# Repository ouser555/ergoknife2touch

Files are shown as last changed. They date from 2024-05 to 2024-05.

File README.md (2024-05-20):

# ergoknife2touch

### imgur link

* imgur pic link
  https://imgur.com/a/k03YgLD
* imgur demo video link
  https://imgur.com/5lGmcCW

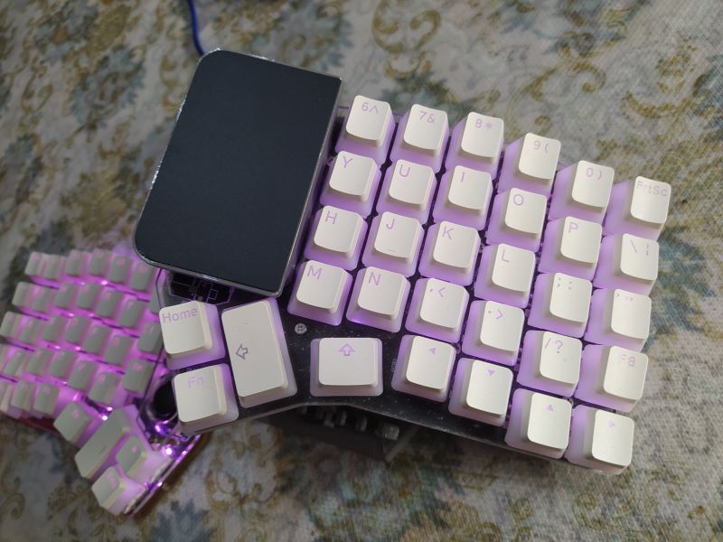
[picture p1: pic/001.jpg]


延續了前一代Ergoknife分體鍵盤，更換了一些性能更強的組件，保留用螺絲調整的傾斜設計。

照片上看到的鍵盤都是一樣的透明色，差別只是有還沒撕膠膜的或是裝了特別的鍵帽，

或是開了燈效，都還是同一組鍵盤。

所有組件都可以靠一隻螺絲起子簡易拆裝的設計，更換部件清潔都很方便。

連接左右鍵盤只需要普通的3.5mm音源線即可，選擇會比較多。

.

* 左手配置一組Trackpoint和OLED螢幕，右手則改成了支援多指的觸控板。

.

* 這次的 Trackpoint 的設計改採用 Joycon 類比搖桿加上trackpad來替代先前的數位壓力式模組，

  精準度與可操控性都有提升，

* 在軟體方面也特別改成可以分別切換左手Trackpoint的功能和右手trackpad的功能

  當前狀態也會顯示在OLED螢幕上。

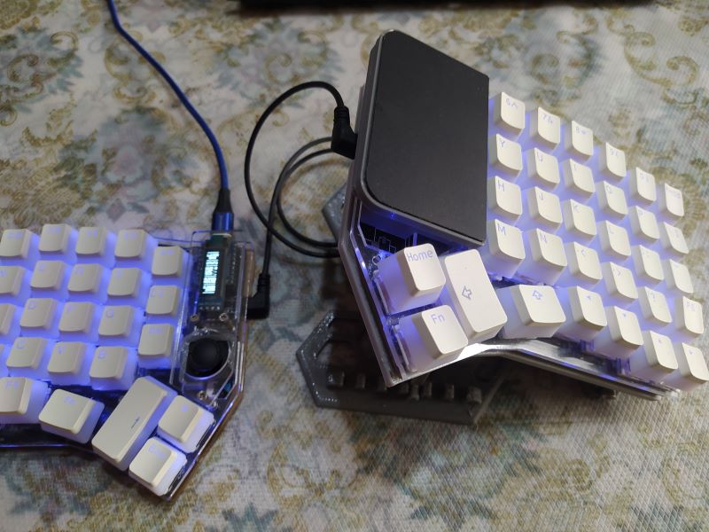
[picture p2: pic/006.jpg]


* 左手trackpoint功能說明

  1. 滑鼠移動

  2. 滾輪上下左右

  3. WASD 四向鍵

  4. UWASD 自訂義四向鍵 可用VIA設定

  5. JOYSTICK R 左搖桿

  6. JOYSTICK R 右搖桿

  7. JOYSTICK Z 板機類比

.

其中搖桿的功能可配合其他搖桿軟體設置更多操作，
	
但此鍵盤並非設定為遊戲用鍵盤，搖桿的設定只是為了提供更多靈活性的考量，
	
所以遊戲使用的精準度就不是在保證的功能範圍內了。

.

搖桿中鍵功能沒有打開，因為該鍵需要的操作力度過大，怕影響機構壽命所以不開放此功能。
	
有這個需求的，剛好自己會改軟體的使用者，可以自己修改，硬體線路都有保留。
	
硬體有預留一組滾輪編碼器/旋轉編碼器的接口，使用者也可以自行飛線改裝。

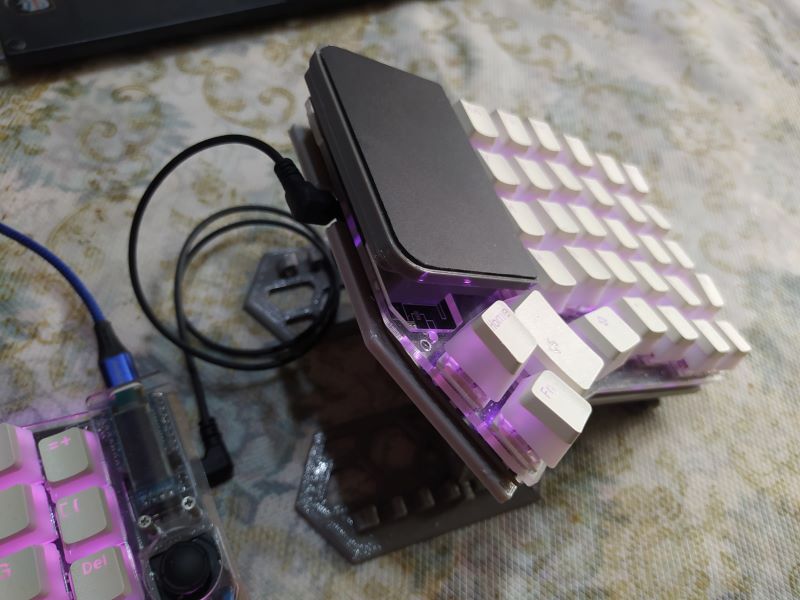
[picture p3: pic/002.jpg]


* 右手trackpad功能說明

  1. 單指滑動為普通滑鼠鼠標。

  2. 單指點擊>滑鼠左鍵。

  3. 雙指點擊>滑鼠右鍵。

  4. 三指按住0.5秒後放開>自定義按鍵 user0，預設為中鍵。

  5. 雙指往四個方向划動>四向滾輪。

  6. 雙指放大縮小>此手勢分別有三種設定

     a. 對普通網頁或編輯器的 zoom in/out，其實就是一般ctrl+滾輪的功能。

     b. 音量調整up/dowm。

     c. 自定義按鍵，user 5、6。 

     d. 關閉此功能，由於某些人可能容易把雙指的滾輪和這個放大縮小的手勢搞混，比方手抖造成的誤操作，所以也讓使用這能夠關閉這個功能。

  7. 單指4向swipe，通過單指快速往四個方向掃掠分別對應到四個可自定義按鍵，user 1、2、3、 4預設為數字小鍵盤4、6、2、8。

     由於這個操作也是要依靠使用者的習慣及熟練度才能有較好的體驗，所以如果想關閉這個功能就直接把user 1、2、3、4鍵依喜好設成無按鍵即可。

  8. 雖然這個觸控板硬體性能可以支援到5指，但此觸控板的機構條件，實在是很難再放下更多手指了，所以這應該是比較合理的配置了。

  9. 為了在這個尺寸上合理的放置觸控板，所以犧牲了3個普通按鍵的鍵位，總按鍵數為35+32=67鍵，

     但觸控板提供的手勢自定義按鍵也達到了7鍵，所以可操控性實質上增加了。

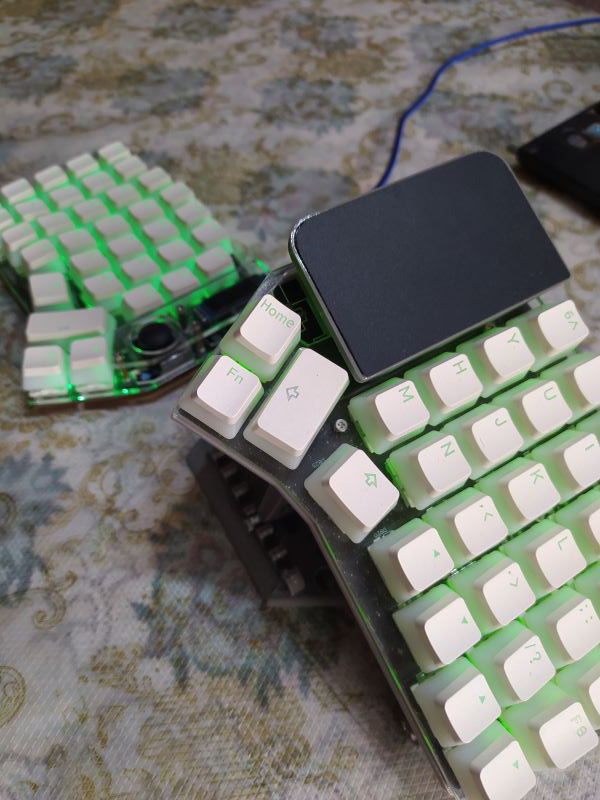
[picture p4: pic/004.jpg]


此款鍵盤打開了大部分的RGB燈效，因為還沒針對此功能拍影片，所以可以先參考連結中其他鍵盤的功能展示

https://www.youtube.com/shorts/bci9zSVapj8  (相似度很高，音效是電腦端發出的)

https://www.youtube.com/watch?v=7f3usatOIKM (分體鍵盤的表現會稍有不同)

.

自己拍的部分效果展示，

https://imgur.com/a/ag3FOmy

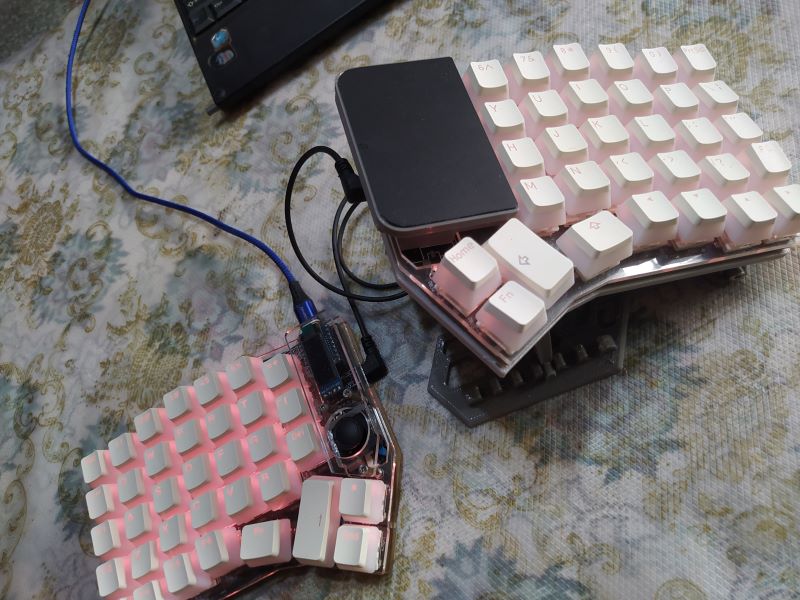
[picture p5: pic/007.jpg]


### 這組鍵盤同樣有提供傾斜架的3D列印檔，有需要可以自行列印。

* 傾斜架 螺絲腳板本

  https://www.printables.com/model/740016-ergoknife2-adjust-tenting-stand

* 傾斜架 普通版本

  https://www.printables.com/model/871241-ergoknife2-adjust-tenting-stand

.

### 預設操作方式

  預設是普通的QWERT配列

  因為所有的按鍵都可以使用者自定義，這裡只說明必要的預設值。

  * Fn鍵

    左右手的Fn鍵為鍵盤中唯一一個1.5U的鍵，

    位置在從拇指邊往外數第三個鍵，

    唯一一個放置角度為35度的鍵。

  * 左搖桿模式設定

    * Master Fn+左往內數邊第二個鍵

  * 右搖桿模式設定

    * Master Fn+左往內數邊第三個鍵

  * RESET鍵

    由於沒有實體RESET鍵，所以設定了功能鍵實現這個功能，

    * Master Fn + 左邊第一個鍵

    * 此鍵盤如果按下RESET則會進入刷機模式，電腦會跳出一個磁碟空間，

      把要刷的UF2檔拖入然後稍等一下即可完成刷機。

      此功能鍵為刷機用，不是單純的RESET鍵，所以沒事不要去按。

    * 右鍵盤手接上USB線也可以用同樣方法操作這個鍵。

.

### VIA configurator 即時改鍵軟體

  * 先從github上下載ergoknife2的json檔

    https://github.com/ouser555/ergoknife2/blob/main/via%20config%20file/ErgoKnife2.json

    右上下角方欄位有一排圖標，中間有個download raw file的圖標，

    點選即可下載。

  * 打開網頁端app

    https://usevia.app/

    進入後可以看到最上方欄位有幾個圖標，點選最的最右邊的齒輪形圖標，

    將Show Design tab選項打開，上方圖標就會多了一個Design可以選擇，

    點選進入，選Load，然後選擇剛剛下載的ergoknife2.json檔，

    即會秀出鍵盤配列。
    
    

    點選最上方的Configure圖標

    再點選Authorize device +，此時如果你的鍵盤已接上電腦，

    就會從跳出的對話框看到usevia.app要求與HID裝置連接，

    當中有一個ergoknife2的鍵盤，點選後鍵盤就能與APP連接。

    
  * 可以看到鍵盤配列下方有兩個十字排列的按鍵，

    十字中間的X是沒有設定功能的，

    十字的四個方向則是UWASD模式的自定義欄位，

    可以嘗試設定按鍵操作看看。

  * 中間下方還有四個按鍵，這是作為滾輪編碼器的功能預留鍵，

    電路有預留功能腳位，目前沒有開放，有要改的可以再來訊討論。

* 開源連結

  https://github.com/ouser555/ergoknife2touch

  ```
  make ergoknife2:via
  ```

  使用的QMK版本 qmk 0.22.13，其他版本不保證能正確運行。

  如果有需要改成最新版本可以參考qmk的changeLog

  https://github.com/qmk/qmk_firmware/tree/master/docs/ChangeLog

  依據它變動的項目去做修改。

## 線路圖


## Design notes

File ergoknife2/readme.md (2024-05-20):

# ergoknife2

ergoknife2
ergoknife2PCB

*A pre-built, split mechanical keyboard with 70 keys based on the RP2040 processor*

* Keyboard Maintainer: [ouer555](https://github.com/ouser555)
* Hardware Supported: *ergoknife split ergonomic keyboard*

Make example for this keyboard (after setting up your build environment):

```sh
    make ergoknife2:via
```

Flashing example for this keyboard:

```sh
    make ergoknife2:via:flash
```
See the [build environment setup](https://docs.qmk.fm/#/getting_started_build_tools) and the [make instructions](https://docs.qmk.fm/#/getting_started_make_guide) for more information. Brand new to QMK? Start with our [Complete Newbs Guide](https://docs.qmk.fm/#/newbs).

## Features
- Highly integrated design with microcontroller, USB and TRRS connectors, and OLED all integrated on the main board with no secondary modules
- RP2040 processor by Raspberry Pi Foundation running at 130 MHz with 16MB flash memory
- 128x32 OLED on each keyboard half
- 70 per-key RGB LEDs are individually addressable
- USB C host connection
- Hot swap connectors for MX switches

## Bootloader

Enter the bootloader in 3 ways:

* **Bootmagic reset**: Hold down the upper left key on the left hand keyboard half or the upper right key on the right hand keyboard half while plugging in USB
* **Physical reset button**: Press the RST button twice, rapidly
* **Keycode in layout**: Press the key mapped to `QK_BOOT` if it is available

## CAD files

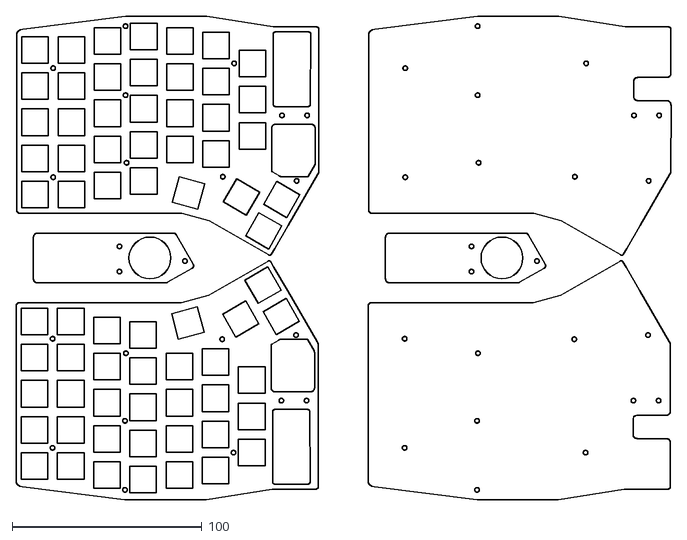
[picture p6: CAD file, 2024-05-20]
acrylic/17.dxf
344.8 x 254.4

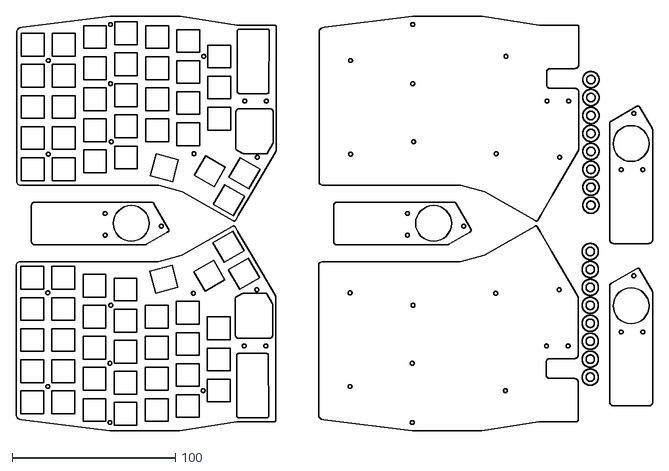
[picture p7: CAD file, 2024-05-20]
acrylic/16.dxf
390.0 x 254.4

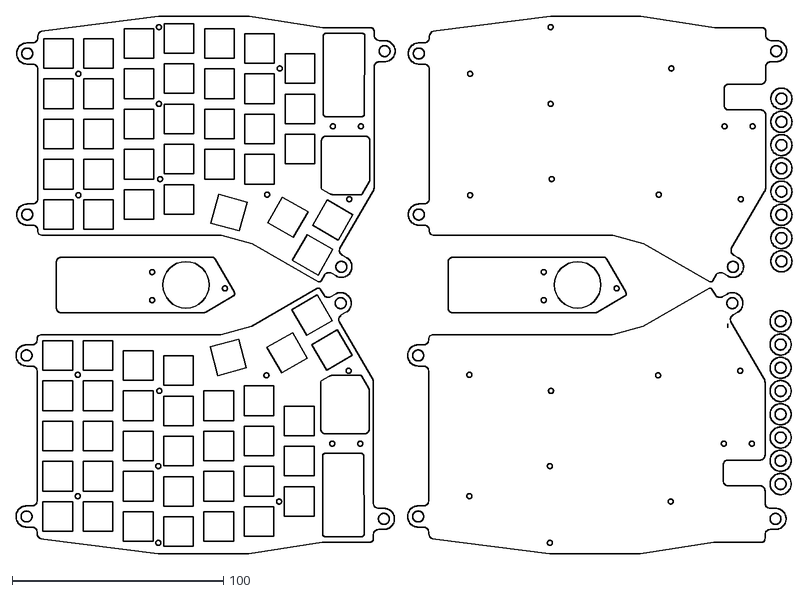
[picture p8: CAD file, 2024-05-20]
acrylic/0015.dxf
367.2 x 254.4

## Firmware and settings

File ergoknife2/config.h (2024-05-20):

/*
 * Copyright 2022 Kevin Gee <info@controller.works>
 * 
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
 * You should have received a copy of the GNU General Public License
 * along with this program.  If not, see <http://www.gnu.org/licenses/>.
 */

#pragma once

#define POINTING_DEVICE_TASK_THROTTLE_MS 10

#define SPLIT_USB_DETECT
#define USB_SUSPEND_WAKEUP_DELAY 1000

#define SPLIT_USB_TIMEOUT 2000
#define SPLIT_USB_TIMEOUT_POLL 10
#define SPLIT_WATCHDOG_ENABLE
#define SPLIT_WATCHDOG_TIMEOUT 3000


#define MK_KINETIC_SPEED
#define MK_MOMENTARY_ACCEL
//#define MK_COMBINED
#define MOUSEKEY_MAX_SPEED      6
#define MOUSEKEY_TIME_TO_MAX    64


#define DYNAMIC_KEYMAP_LAYER_COUNT 6

#define WS2812_PIO_USE_PIO1
#define RGB_MATRIX_LED_COUNT 70
#define RGB_MATRIX_SPLIT { 35, 35 }

#define SPLIT_TRANSPORT_MIRROR
#define SPLIT_LAYER_STATE_ENABLE
#define SPLIT_LED_STATE_ENABLE
#define SPLIT_MODS_ENABLE

//#define MOUSE_EXTENDED_REPORT

#define SPLIT_POINTING_ENABLE
#define POINTING_DEVICE_COMBINED

//#define ADNS5050_SCLK_PIN   GP10 
//#define ADNS5050_SDIO_PIN   GP9
//#define ADNS5050_CS_PIN     GP11
//#define POINTING_DEVICE_INVERT_Y

//#define ENCODERS_PAD_A { GP12 }
//#define ENCODERS_PAD_B { GP13 }
//#define ENCODER_TESTS

//#define I2C_DRIVER I2CD0
//#define I2C1_SDA_PIN GP6
//#define I2C1_SCL_PIN GP7

#define I2C_DRIVER I2CD1
#define I2C1_SDA_PIN GP6
#define I2C1_SCL_PIN GP7

// Min 0, max 32
#define JOYSTICK_BUTTON_COUNT 16
// Min 0, max 6: X, Y, Z, Rx, Ry, Rz
#define JOYSTICK_AXIS_COUNT 6
// Min 8, max 16
//#define JOYSTICK_AXIS_RESOLUTION 10 // for AVR
#define JOYSTICK_AXIS_RESOLUTION 12 // 12-bit for most STM32
//#define JOYSTICK_AXIS_RESOLUTION 8 // 12-bit for most STM32

#define ANALOG_JOYSTICK_X_AXIS_PIN GP27
#define ANALOG_JOYSTICK_Y_AXIS_PIN GP26

#define ANALOG_JOYSTICK_AXIS_MAX 800
#define ANALOG_JOYSTICK_AXIS_MIN 200

#define _MIN 190
#define _MAX 820
#define _J_REP_MAX 2047
#define _CENTER 550
#define _J_DEADZONE 10
//#define _MAX 1023
//#define _CENTER 512
#define _DEAD 100
#define _SHIFT 15 // last 15 steps upwards

#define _DOWN_TRESHOLD (_CENTER+_DEAD)
#define _UP_TRESHOLD (_CENTER-_DEAD)

#define _TRESHOLD 40


#define JSV ANALOG_JOYSTICK_Y_AXIS_PIN
#define JSH ANALOG_JOYSTICK_X_AXIS_PIN

#ifdef OLED_ENABLE
#define OLED_DISPLAY_128X32
#define OLED_BRIGHTNESS 128
//#define OLED_FONT_H "keyboards/mlego/m65/lib/glcdfont.c"
#endif

#define AZOTEQ_IQS5XX_WIDTH_MM 75
#define AZOTEQ_IQS5XX_HEIGHT_MM 47

#define AZOTEQ_IQS5XX_RESOLUTION_X 768
#define AZOTEQ_IQS5XX_RESOLUTION_Y 1280

//#define POINTING_DEVICE_INVERT_Y

//#define AZOTEQ_IQS5XX_ROTATION_90
//#define AZOTEQ_IQS5XX_ROTATION_180
#define AZOTEQ_IQS5XX_ROTATION_270


//split not support
//#define POINTING_DEVICE_MOTION_PIN GP28
//#define POINTING_DEVICE_MOTION_PIN_ACTIVE_LOW

//#define AZOTEQ_IQS5XX_TAP_ENABLE false
//#define AZOTEQ_IQS5XX_TWO_FINGER_TAP_ENABLE false
#define AZOTEQ_IQS5XX_PRESS_AND_HOLD_ENABLE true
#define AZOTEQ_IQS5XX_SWIPE_X_ENABLE true
#define AZOTEQ_IQS5XX_SWIPE_Y_ENABLE true
#define AZOTEQ_IQS5XX_ZOOM_ENABLE true
//#define AZOTEQ_IQS5XX_SCROLL_ENABLE false
//
#define AZOTEQ_IQS5XX_TAP_TIME 200
//#define AZOTEQ_IQS5XX_TAP_DISTANCE 25
//#define AZOTEQ_IQS5XX_HOLD_TIME 300
#define AZOTEQ_IQS5XX_SWIPE_INITIAL_TIME 150
#define AZOTEQ_IQS5XX_SWIPE_INITIAL_DISTANCE 400 
//#define AZOTEQ_IQS5XX_SWIPE_CONSECUTIVE_TIME 0
//#define AZOTEQ_IQS5XX_SWIPE_CONSECUTIVE_DISTANCE 2000
#define AZOTEQ_IQS5XX_SCROLL_INITIAL_DISTANCE 15
#define AZOTEQ_IQS5XX_ZOOM_INITIAL_DISTANCE 50
#define AZOTEQ_IQS5XX_ZOOM_CONSECUTIVE_DISTANCE 25

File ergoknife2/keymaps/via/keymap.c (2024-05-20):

/*
 * Copyright 2022 Kevin Gee <info@controller.works>
 * 
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
 * You should have received a copy of the GNU General Public License
 * along with this program.  If not, see <http://www.gnu.org/licenses/>.
 */
#include QMK_KEYBOARD_H

//#include "pmw3610.h"
#include "analog.h"
#include "pointing_device.h"
//#include "./drivers/sensors/adns5050.h"
#include "./drivers/sensors/analog_joystick.h"
#include "sub_joystick.h"
//#include "transactions.h"
//#include "print.h"
#include "azoteq_iqs5xx.h"

enum layers {
    _BASE = 0,
    _LOWER,
    _RAISE,
    _ADJUST,
    _EXTRA01,
    _EXTRA02
};

enum custom_keycodes {
#ifdef VIA_ENABLE
  //QWERTY = USER00,
  BASE = QK_KB_0,
  //QWERTY = CS00, // qmk v1.1.1
#else
  QWERTTY = SAFE_RANGE,
#endif
  LOWER,
  RAISE,
  ADJUST,
  EXTRA01,
  EXTRA02,
  MJMODE,
  SJMODE,
  JOYRST
};

enum jmodes {
    _MOUSE = 0,
    _SCROLL,
    _WASD,
    _UWASD,
    _JOYSL,
    _JOYSR,
    _JOYSZ,
};

enum zmodes {
    _ZZOOM = 0,
    _ZVOLUM,
    _ZCUSTOM,
    _ZDISABLE,
};

typedef union {
  uint32_t raw;
  struct {
    uint8_t MjMode;
    uint8_t SjMode;
  };
} user_config_t;

user_config_t user_config;
uint8_t MjMode;
uint8_t SjMode;

typedef struct {
    int8_t jdx;
    int8_t jdy;
} report_jdelta_t;

report_jdelta_t master;
report_jdelta_t slave;


#if 0
void joysitck_mode_master_INC(void) {
  if(MjMode == _JOYSZ) {
    MjMode = _MOUSE;
  }else{
    MjMode++;
    if(MjMode == SjMode && MjMode > _UWASD){
      if(MjMode == _JOYSZ) {
        MjMode = _MOUSE;
      }else{
        MjMode++;
      }
    }
  }
}

void joysitck_mode_slave_INC(void) {
  if(SjMode == _JOYSZ) {
    SjMode = _MOUSE;
  }else{
    SjMode++;
    if(MjMode == SjMode && SjMode > _UWASD){
      if(SjMode == _JOYSZ) {
        SjMode = _MOUSE;
      }else{
        SjMode++;
      }
    }
  }
}
#else

void joysitck_mode_master_INC(void) {
  if(MjMode == _JOYSZ) {
    MjMode = _MOUSE;
  }else{
    MjMode++;
  }
}

void zoom_mode_slave_INC(void){
  if(SjMode == _ZDISABLE) {
    SjMode = _ZZOOM;
  }else{
    SjMode++;
  }
}
#endif

int16_t xOrigin, yOrigin;
#if 0
int16_t XUpThreshold = 0;
int16_t XDownThreshold = 0;
int16_t YUpThreshold = 0;
int16_t YDownThreshold = 0;
#endif

void JoyOriginReset(void){
  xOrigin = analogReadPin(JSH);
  yOrigin = analogReadPin(JSV);
  //XUpThreshold   = xOrigin - _DEAD;
  //XDownThreshold = xOrigin + _DEAD;
  //YUpThreshold   = yOrigin - _DEAD;
  //YDownThreshold = yOrigin + _DEAD;
}

#define TRACKPAD_THREE_FINGER_CLICK_TIME 300 //300ms

#define SCROLL_DIVISOR_H 8.0
#define SCROLL_DIVISOR_V 8.0

#define EISU LALT(KC_GRV)

#define CONSTRAIN_HID(amt) ((amt) < INT8_MIN ? INT8_MIN : ((amt) > INT8_MAX ? INT8_MAX : (amt)))
#define CONSTRAIN_HID_XY(amt) ((amt) < XY_REPORT_MIN ? XY_REPORT_MIN : ((amt) > XY_REPORT_MAX ? XY_REPORT_MAX : (amt)))

static i2c_status_t azoteq_iqs5xx_init_status = 1;

const uint16_t PROGMEM keymaps[][MATRIX_ROWS][MATRIX_COLS] = {

  /* Qwerty
   * ,----------------------------------------------------------------------------------------------------------------------.
   * | ESC  |   1  |   2  |   3  |   4  |   5  |   [  |                    |   ]  |   6  |   7  |   8  |   9  |   0  |Pscree|
   * |------+------+------+------+------+------+------+--------------------+------+------+------+------+------+------+------|
   * |  `   |   Q  |   W  |   E  |   R  |   T  |   -  |                    |   =  |   Y  |   U  |   I  |   O  |   P  |  \   |
   * |------+------+------+------+------+------+------+--------------------+------+------+------+------+------+------+------|
   * | Tab  |   A  |   S  |   D  |   F  |   G  |  Del |                    | Bksp |   H  |   J  |   K  |   L  |   ;  |  "   |
   * |------+------+------+------+------+------+---------------------------+------+------+------+------+------+------+------|
   * | Shift|   Z  |   X  |   C  |   V  |   B  | Space|                    | Enter|   N  |   M  |   ,  |   .  |   /  | Shift|
   * |-------------+------+------+------+------+------+------+------+------+------+------+------+------+------+-------------|
   * | Ctrl |  GUI |  ALt | EISU |||||||| Lower| Space|  Del |||||||| Bksp | Enter| Raise|||||||| Left | Down |  Up  | Right|
   * ,----------------------------------------------------------------------------------------------------------------------.
   */
  [_BASE] = LAYOUT_7x5x2(
    KC_ESC,  KC_1,    KC_2,    KC_3,    KC_4,    KC_5,    KC_LBRC,                        KC_RBRC, KC_6,    KC_7,    KC_8,    KC_9,    KC_0,    KC_PSCR,
    KC_GRV,  KC_Q,    KC_W,    KC_E,    KC_R,    KC_T,    KC_MINS,                        KC_EQL , KC_Y,    KC_U,    KC_I,    KC_O,    KC_P,    KC_BSLS,
    KC_TAB,  KC_A,    KC_S,    KC_D,    KC_F,    KC_G,    KC_DEL,                         KC_BSPC, KC_H,    KC_J,    KC_K,    KC_L,    KC_SCLN, KC_QUOT,
    KC_LSFT, KC_Z,    KC_X,    KC_C,    KC_V,    KC_B,    KC_SPC,                         KC_ENT , KC_N,    KC_M,    KC_COMM, KC_DOT,  KC_SLSH, KC_RSFT,
    KC_LCTL, KC_LGUI, KC_LALT, EISU,             LOWER,   KC_SPC , KC_DEL,        KC_BSPC,KC_ENT , RAISE,            KC_LEFT, KC_DOWN, KC_UP,   KC_RGHT,
    _______, _______,    KC_X, _______, _______, _______,_______,                         _______, _______, _______, _______, _______, _______, _______
  ),
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

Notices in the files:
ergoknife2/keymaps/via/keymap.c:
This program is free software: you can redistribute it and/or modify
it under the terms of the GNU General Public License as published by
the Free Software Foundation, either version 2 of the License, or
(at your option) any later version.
